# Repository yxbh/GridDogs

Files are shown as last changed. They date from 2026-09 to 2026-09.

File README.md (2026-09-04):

# GridDogs — parametric tool-anchor tiles for Gridfinity

**Pegboard tiles that drop into any Gridfinity baseplate, plus press-fit anchor pegs that
fence your tools in place.** Everything is generated from a single Python script, so every
dimension is customisable.

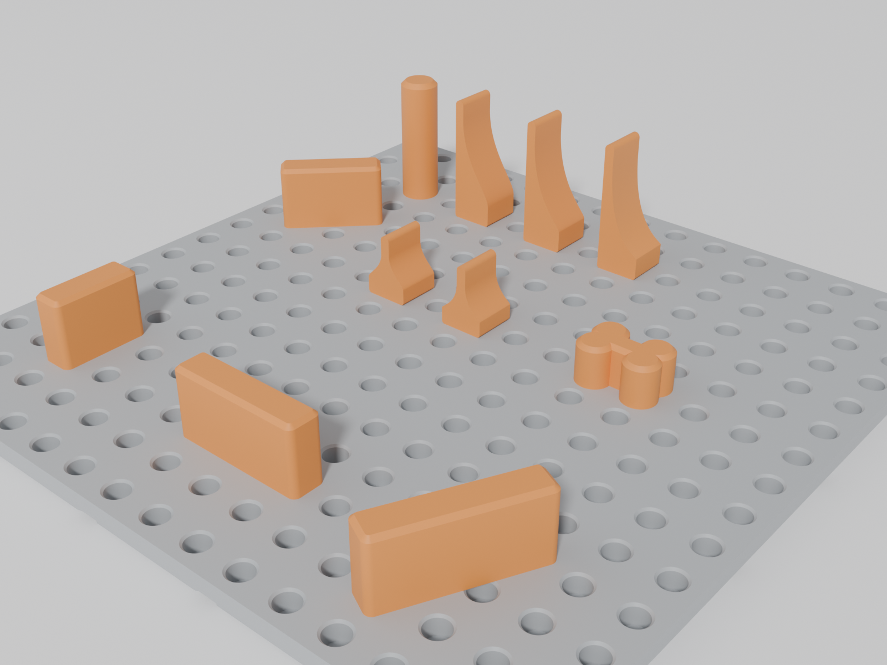
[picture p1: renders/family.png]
GridDogs family


## The idea

GridDogs combines a pegboard-style tool-retention system with the standard Gridfinity
mounting interface:

- **Tiles** are pegboard plates with standard Gridfinity feet underneath — they drop
  straight into any Gridfinity baseplate, which gives X/Y registration for free.
- **Anchors** are press-fit pegged parts that plug into the tile holes to fence tools in.
  The name comes from woodworking bench dogs.

GridDogs is *inspired by* [GridLock](https://get.gridlocksystem.com) and
[Gridfinity](https://gridfinity.xyz) (by Zack Freedman); it is not affiliated with or
endorsed by either. Its 14 mm anchor lattice is derived directly from the 42 mm
Gridfinity pitch (`42 / 3`), and its geometry is independently designed.

## Parts

| Part | Footprint | Notes |
| --- | --- | --- |
| `tile_{cols}x{rows}_gridfinity.stl` | Up to 293.5 × 293.5 mm | Every unique rectangle where `1 ≤ cols ≤ rows ≤ 7`; rotate for the opposite orientation |
| `anchor_round_bumper_{20,40}mm.stl` | 12 mm ⌀ | Single-peg round bumper with a 6.6 mm grip ridge |
| `anchor_wall_short_{20,40}mm.stl` | 26 × 10 mm | Short fence wall with two solid end pegs |
| `anchor_wall_long_{20,40}mm.stl` | 40 × 10 mm | Long fence wall with two solid end pegs and no centre peg |
| `anchor_wall_diagonal_2x2_{20,40}mm.stl` | 31.8 × 10 mm | Diagonal wall spanning a 2×2 group of holes |
| `anchor_wall_diagonal_2x3_{20,40}mm.stl` | 43.3 × 10 mm | Diagonal wall spanning a 2×3 group of holes |
| `anchor_curve_standard_{20,40}mm.stl` | 13.5 × 13.5 mm | General-purpose single-peg curved stop with a grip ridge |
| `anchor_curve_deep_{20,40}mm.stl` | 13.5 × 13.5 mm | Deeper single-peg curved stop with a grip ridge |
| `anchor_curve_bowl_{20,40}mm.stl` | 13.5 × 13.5 mm | Most aggressively scooped single-peg curved stop with a grip ridge |
| `anchor_curve_centre_standard_{20,40}mm.stl` | 13.5 × 13.5 mm | Double-sided single-peg curve with a centred peak and grip ridge |
| `anchor_curve_centre_deep_{20,40}mm.stl` | 13.5 × 13.5 mm | Deep double-sided single-peg curve with a centred peak and grip ridge |
| `anchor_bone.stl` | 24 × 17 mm | The mascot — dog-bone anchor, two pegs |
| `fit_test_coupon.stl` | 76 × 15 mm | Optional comparison strip, holes `HOLE_D ± 0.2 mm` |

Tile holes are 6.5 mm ⌀ × 5.5 mm deep blind holes on a 14 mm pitch (3 × 3 holes per
42 mm Gridfinity cell). Round and curved single-peg anchors use a 5.3 mm-long slotted
shaft with a 6.6 mm grip ridge. Wall anchors use physically tested solid 6.5 mm ⌀ ×
5.3 mm end pegs. The two-peg bone retains its shorter slotted pegs. All pegs use a
clearance-fit 7.5 mm root flare and land on the 14 mm lattice—even across adjoining
tile boundaries.

Diagonal walls use the same two solid end pegs as straight walls. The `2x2` version
connects holes one column and one row apart; the `2x3` version connects holes one column
and two rows apart. Their round pegs let each wall align naturally in either diagonal
direction as it is inserted.

## Printing

| Part | Layers | Walls | Infill | Supports | Material |
| --- | --- | --- | --- | --- | --- |
| Tiles | 0.2 mm | 3 | 10–15 % | None | PLA or PETG |
| Round, wall and bone anchors | 0.2 mm | 4 | any | None | PETG grips better than PLA |
| Curved anchors | 0.2 mm | 4 | any | Under the peg only | PETG grips better than PLA |

All STLs export in print orientation. Tiles print feet-down. Round, wall and bone anchors
print head-down with their pegs pointing upwards, so each peg grows from the supported
head and needs no support. The round and wall anchors are tall and narrow; use a 5 mm
brim.

The five curved profiles export **lying on their sides** so their profile walls print
cleanly. Their pegs are horizontal in this orientation and therefore need painted or
manual support beneath the peg only. A small flat provides a clean support interface,
and the compression slot is rotated so the press-fit crowns remain on vertical printed
walls. Being single-peg, directional curves can be aimed at any angle, but a firm knock
can swivel them; use a multi-peg wall where orientation must not move.

Functional anchors are exported in two heights: 20 mm for low-profile tools and 40 mm
for thicker handles and deeper objects. The 12 mm mascot bone is the only exception.

### Magnets (optional)

Magnet pockets are disabled by default. Set `MAGNETS = True` to add Gridfinity-standard
positions in the underside of the feet (6.3 mm ⌀ × 2.4 mm pockets for 6 × 2 mm magnets,
four per cell at 26 mm spacing). Seat or glue magnets flush with the foot face. They help
retain the tile only on a steel or magnet-equipped baseplate; they do nothing against a
plain plastic baseplate.

## Customising

Everything is driven by the `PARAMS` block at the top of
[`griddogs.py`](griddogs.py) — grid pitch, plate thickness, hole size and pitch, peg
dimensions, wall heights, magnet pockets, and the list of tile sizes to generate
(`TILES` accepts arbitrary `(cols, rows)` pairs).

The default peg shaft and hole are both 6.5 mm nominally. Single-peg anchors add a
6.6 mm rounded grip ridge to their flexible shaft, while the rounded slot termination
and solid root bridge improve strength. Wall anchors instead use two solid end pegs
because physical testing showed that slotted wall pegs could break during removal. The
peg is the preferred fit-tuning dimension because anchors are much cheaper to reprint
than tiles. If your printer or material needs a different fit, adjust `PEG_D`; the
comparison strip is not an exact thermal proxy for a full tile.
The notch count is the size index: one notch is `HOLE_D - 0.2 mm`, three is `HOLE_D`,
and five is `HOLE_D + 0.2 mm`.

The included 7×7 tile is 293.5 mm square and fits the Bambu Lab H2D's official
[325 × 320 mm single-nozzle build area](https://bambulab.com/en-us/h2d/tech-specs).
An 8×8 tile would be 335.5 mm square and does not fit.

```bash
uv run griddogs.py
```

Regenerates every STL into `stl/` and prints a watertight check, bounding box, and
volume for each part. If you don't use [uv](https://docs.astral.sh/uv/), a plain
`pip install manifold3d trimesh numpy` and `python3 griddogs.py` works too.

## Development

```bash
uv sync          # create the venv and install dependencies
uv run griddogs.py   # regenerate STLs
uv run python -m unittest tests.test_geometry
uv run ruff check .  # lint
```

Preview renders are generated headless with [Blender](https://www.blender.org):

```bash
blender --background --factory-startup --python render_previews.py
```

## Licence

[MIT](LICENSE). GridLock is a trademark of its respective owner; GridDogs is an
independent, unaffiliated open-source project.

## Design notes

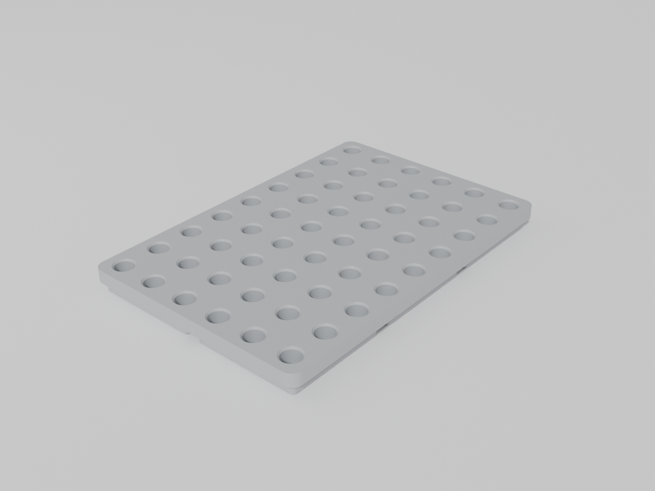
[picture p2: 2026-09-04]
renders/tile_2x3_gridfinity.png

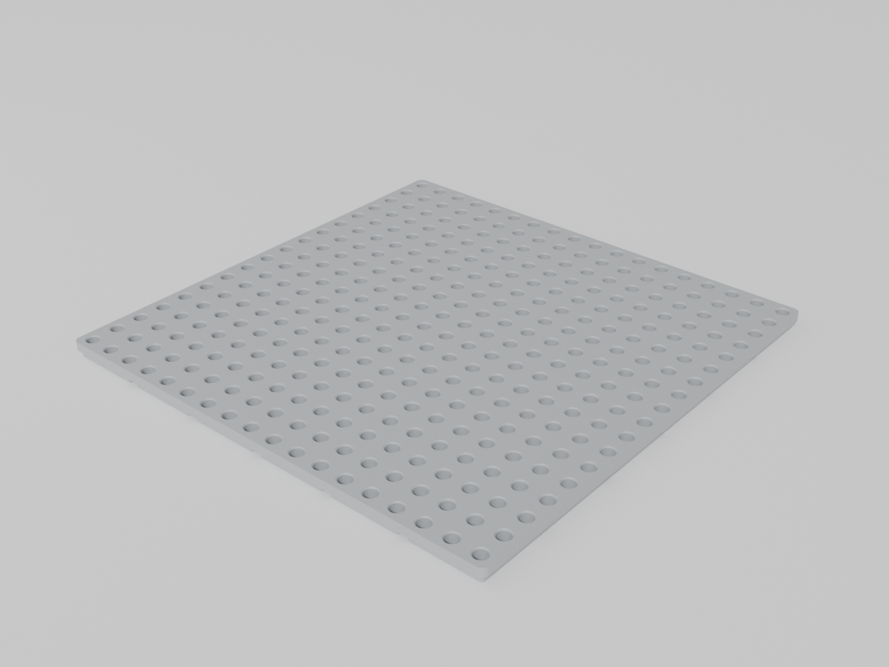
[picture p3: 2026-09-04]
renders/tile_6x6_gridfinity.png

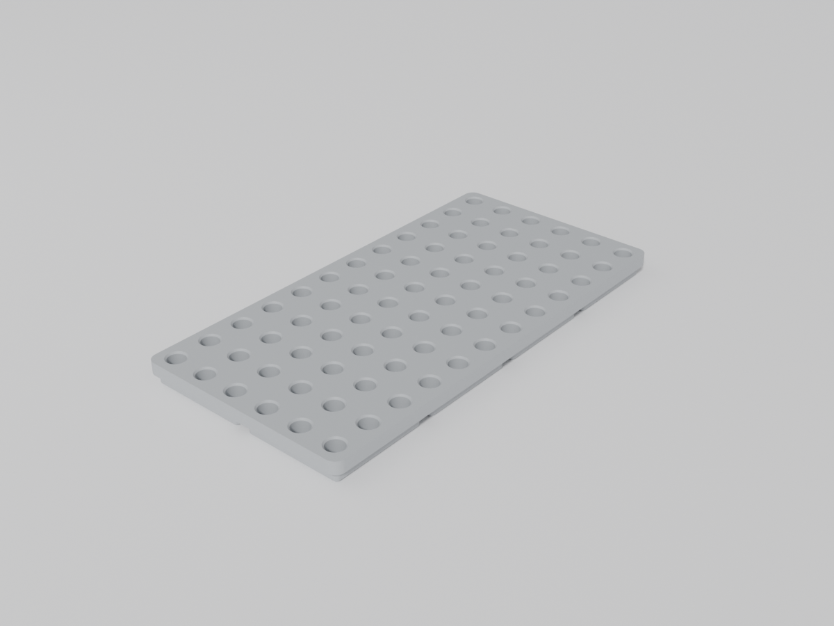
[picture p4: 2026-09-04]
renders/tile_2x4_gridfinity.png

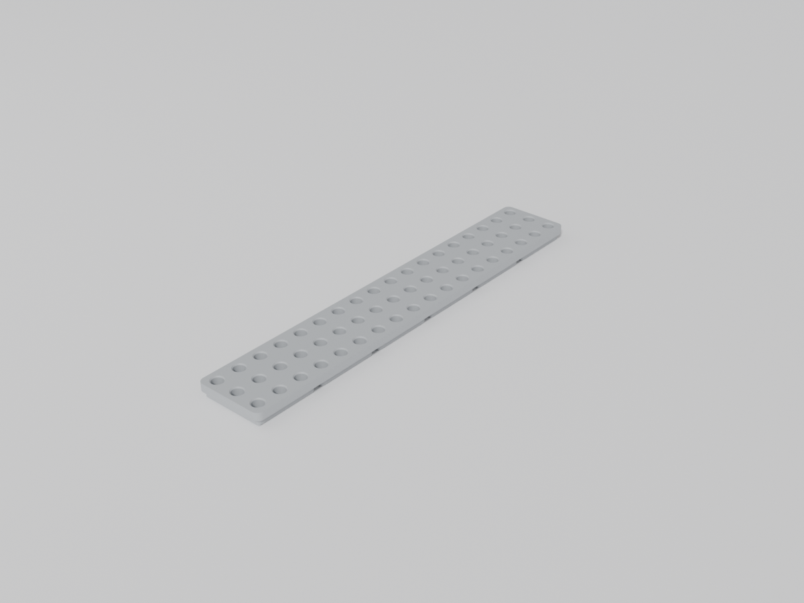
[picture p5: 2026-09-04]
renders/tile_1x6_gridfinity.png

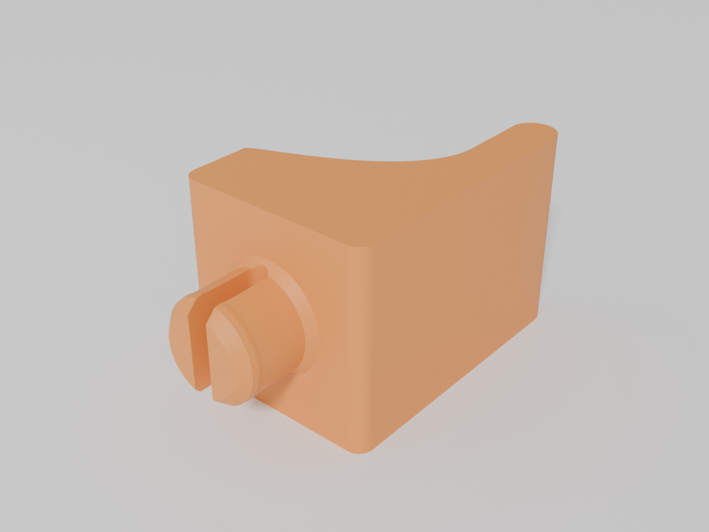
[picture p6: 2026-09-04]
renders/anchor_curve_deep_20mm.png

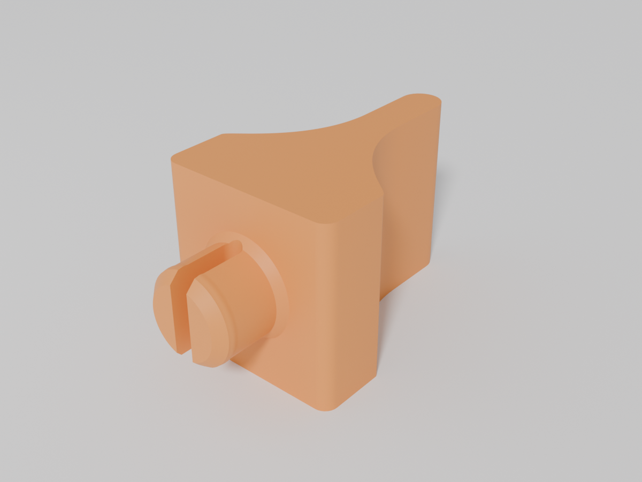
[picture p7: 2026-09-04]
renders/anchor_curve_centre_deep_20mm.png

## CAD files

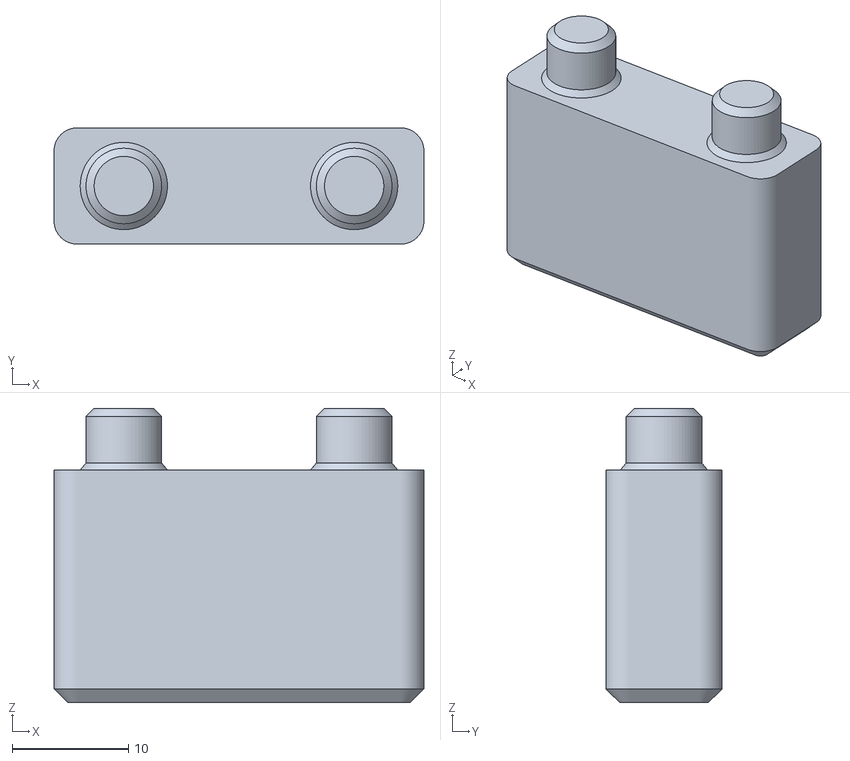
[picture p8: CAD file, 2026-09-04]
stl/anchor_wall_diagonal_2x2_20mm.stl
31.8 x 10.0 x 25.3

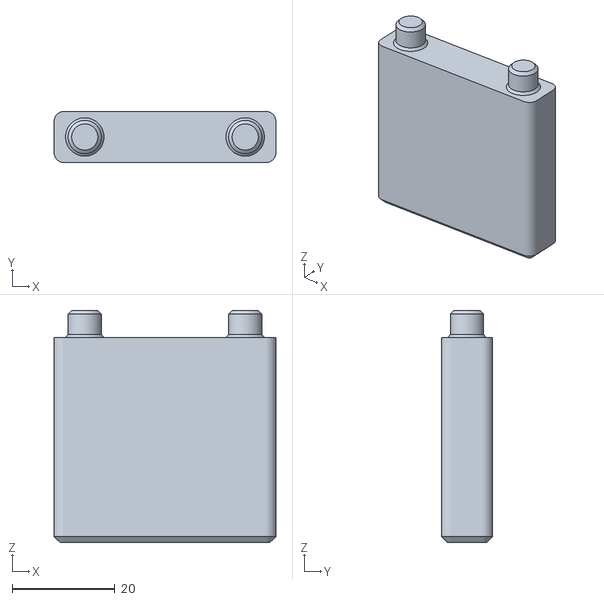
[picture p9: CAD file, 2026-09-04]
stl/anchor_wall_diagonal_2x3_40mm.stl
43.3 x 10.0 x 45.3

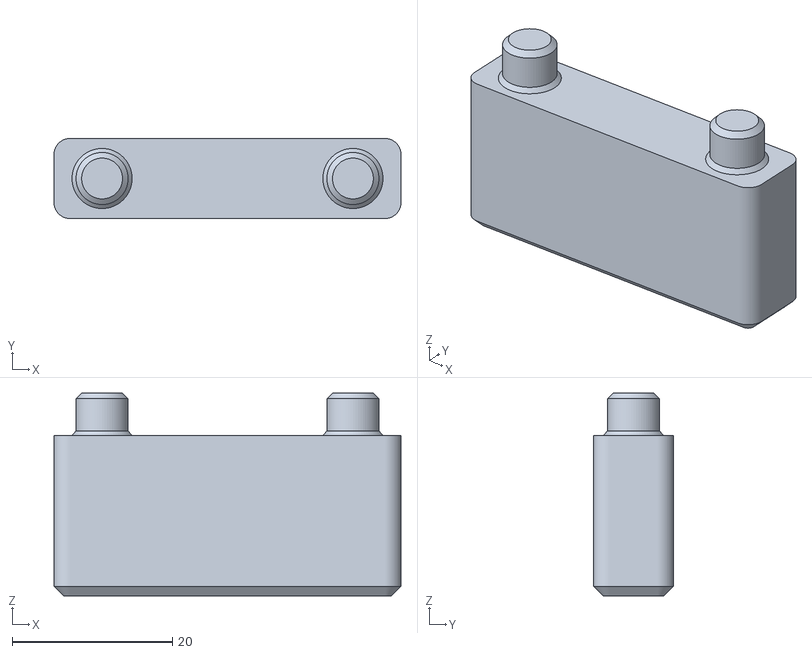
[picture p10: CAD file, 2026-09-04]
stl/anchor_wall_diagonal_2x3_20mm.stl
43.3 x 10.0 x 25.3

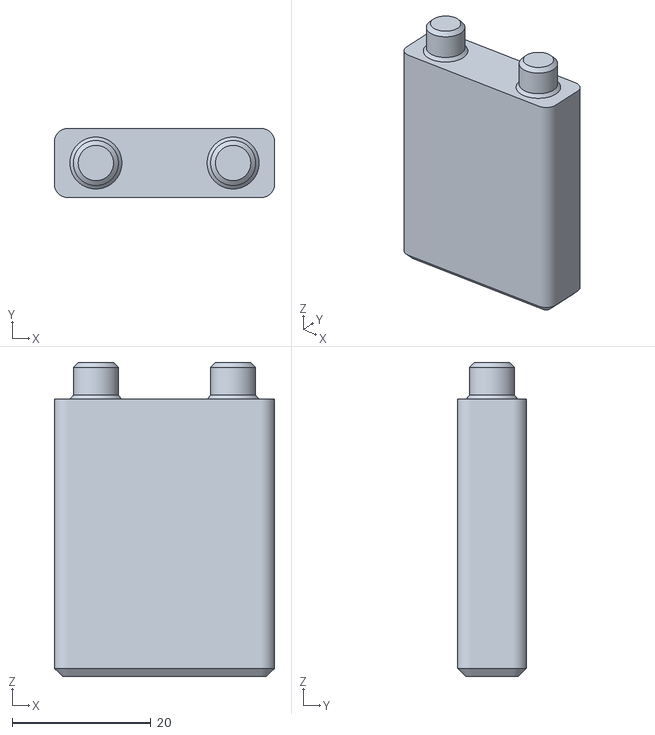
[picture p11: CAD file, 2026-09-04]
stl/anchor_wall_diagonal_2x2_40mm.stl
31.8 x 10.0 x 45.3

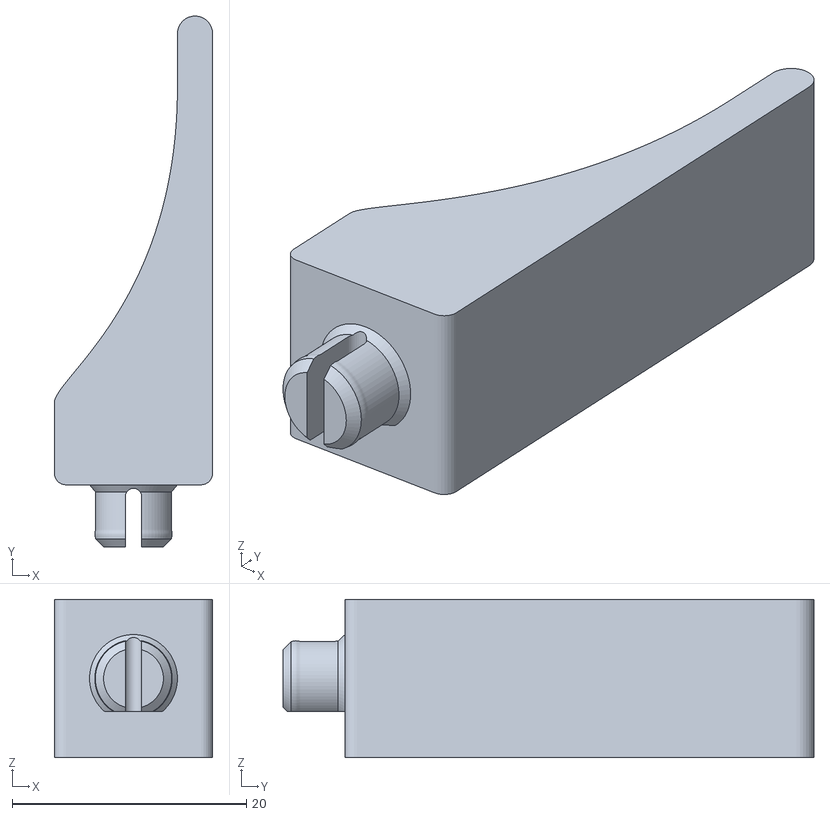
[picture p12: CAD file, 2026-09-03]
stl/anchor_curve_deep_40mm.stl
13.5 x 45.3 x 13.5

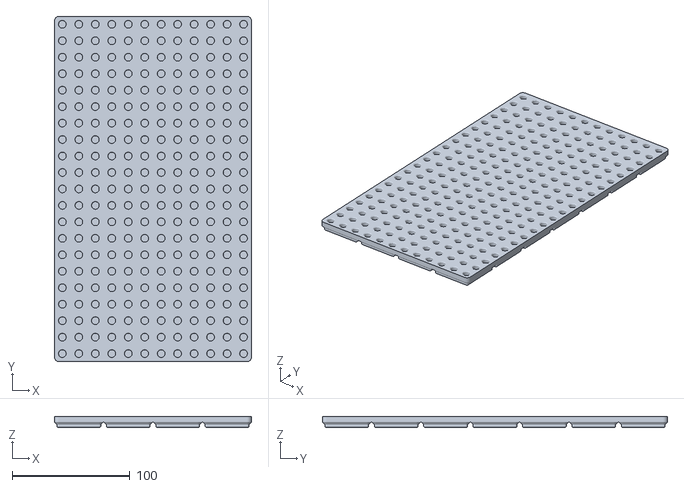
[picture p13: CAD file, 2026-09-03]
stl/tile_4x7_gridfinity.stl
167.5 x 293.5 x 9.50

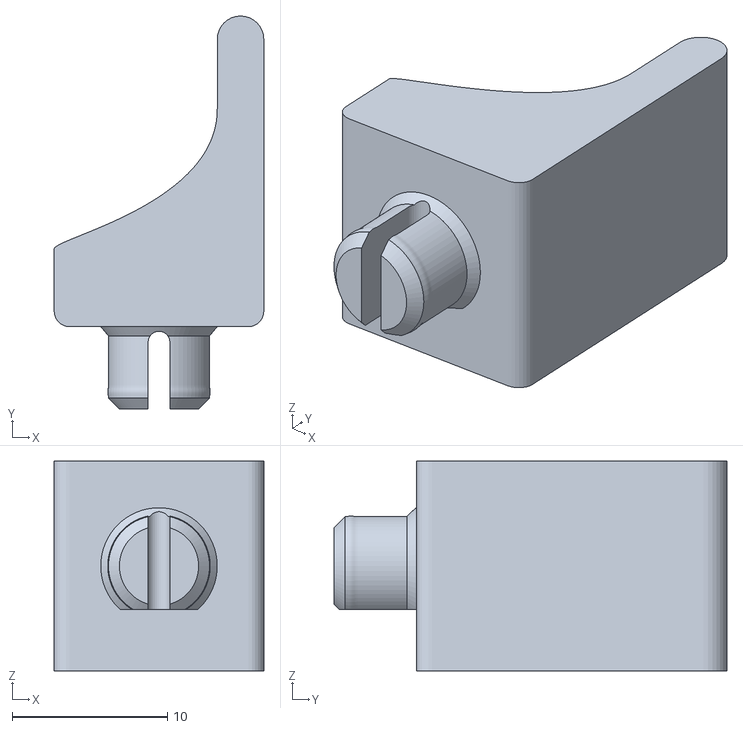
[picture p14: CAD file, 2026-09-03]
stl/anchor_curve_deep_20mm.stl
13.5 x 25.3 x 13.5

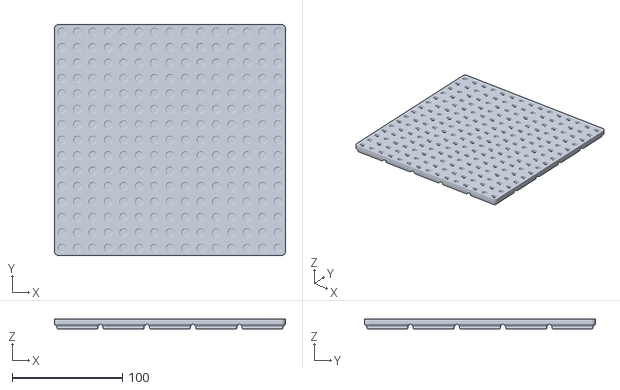
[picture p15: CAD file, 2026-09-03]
stl/tile_5x5_gridfinity.stl
209.5 x 209.5 x 9.50

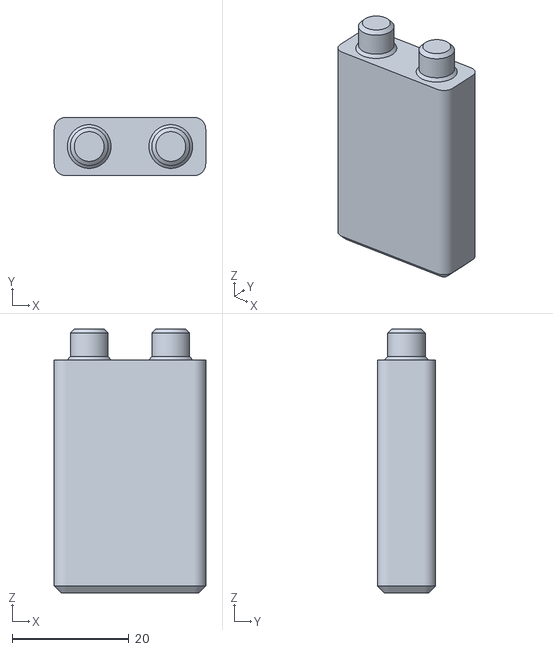
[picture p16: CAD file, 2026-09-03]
stl/anchor_wall_short_40mm.stl
26.0 x 10.0 x 45.3

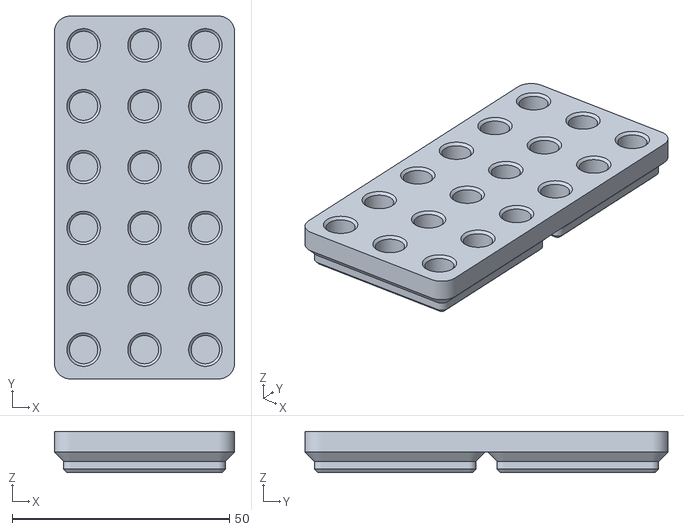
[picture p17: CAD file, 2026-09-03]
stl/tile_1x2_gridfinity.stl
41.5 x 83.5 x 9.50

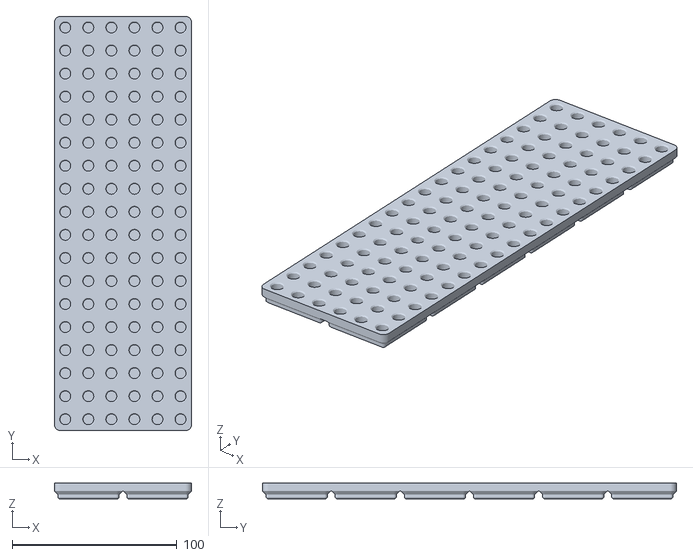
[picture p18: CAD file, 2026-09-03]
stl/tile_2x6_gridfinity.stl
83.5 x 251.5 x 9.50

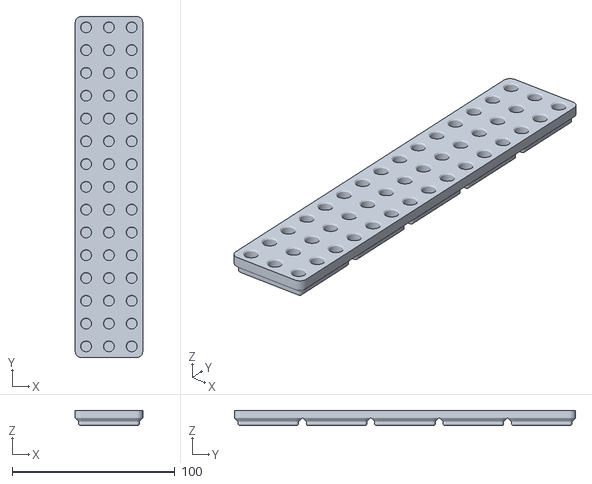
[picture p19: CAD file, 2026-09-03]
stl/tile_1x5_gridfinity.stl
41.5 x 209.5 x 9.50

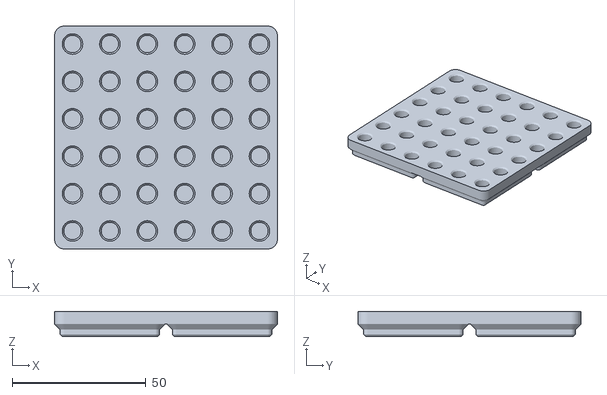
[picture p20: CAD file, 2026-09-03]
stl/tile_2x2_gridfinity.stl
83.5 x 83.5 x 9.50

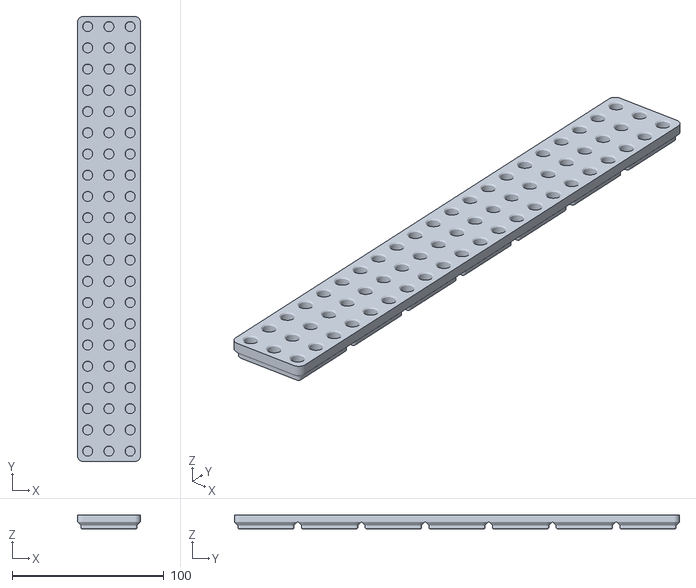
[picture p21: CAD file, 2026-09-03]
stl/tile_1x7_gridfinity.stl
41.5 x 293.5 x 9.50

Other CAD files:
stl/anchor_curve_centre_deep_40mm.stl
stl/tile_1x1_gridfinity.stl
stl/tile_2x3_gridfinity.stl
stl/tile_6x7_gridfinity.stl
stl/anchor_bone.stl
stl/anchor_curve_bowl_20mm.stl
stl/anchor_curve_bowl_40mm.stl
stl/anchor_curve_centre_deep_20mm.stl
stl/anchor_curve_centre_standard_20mm.stl
stl/anchor_curve_centre_standard_40mm.stl
stl/anchor_curve_standard_20mm.stl
stl/anchor_curve_standard_40mm.stl
stl/anchor_round_bumper_20mm.stl
stl/anchor_round_bumper_40mm.stl
stl/anchor_wall_long_20mm.stl
stl/anchor_wall_long_40mm.stl
stl/anchor_wall_short_20mm.stl
stl/fit_test_coupon.stl
stl/tile_1x3_gridfinity.stl
stl/tile_1x4_gridfinity.stl
stl/tile_1x6_gridfinity.stl
stl/tile_2x4_gridfinity.stl
stl/tile_2x5_gridfinity.stl
stl/tile_2x7_gridfinity.stl
stl/tile_3x3_gridfinity.stl
stl/tile_3x4_gridfinity.stl
stl/tile_3x5_gridfinity.stl
stl/tile_3x6_gridfinity.stl
stl/tile_3x7_gridfinity.stl
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

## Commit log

2026-08-23 Add the parametric tile and anchor generator
    Generate Gridfinity-footed tiles on a 14 mm anchor lattice, reinforced press-fit anchors in 20 mm and 40 mm heights, and geometry regression tests.
    Copilot-Session: 0bd1250b-d929-4d53-9f9b-56e7f5108f3c
2026-08-23 Document GridDogs parts and printing
    Describe the tile catalogue, anchor variants, honest support requirements, customisation, H2D limits, and project attribution.
    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
2026-08-23 Add generated STL catalogue
    Include all 28 H2D-compatible rectangular tiles, reinforced anchor variants, the mascot, and the optional fit comparison strip.
    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
    [anchor_bone.stl, anchor_curve_bowl_20mm.stl, anchor_curve_bowl_40mm.stl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]
2026-08-23 Add generated preview renders
    Include one preview per STL and the complete anchor-family hero render.
    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
2026-08-28 Reinforce anchor peg roots
    Use matched 6.5 mm peg and hole diameters, add a solid rounded slot termination at the peg root, disable magnets by default, and refresh generated parts and previews.
    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
    [anchor_bone.stl, anchor_curve_bowl_20mm.stl, anchor_curve_bowl_40mm.stl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]
2026-09-03 Adopt tested anchor peg designs
    Deepen tile holes to 5.5 mm, use solid 6.5 x 5.3 mm end pegs on wall anchors, and apply the 6.6 mm grip ridge to all single-peg anchors. Rename wall outputs and refresh generated STLs and previews.
    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
    [anchor_bone.stl, anchor_curve_bowl_20mm.stl, anchor_curve_bowl_40mm.stl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]
2026-09-04 Add diagonal wall anchors
    Generate 2x2 and 2x3 diagonal walls at both standard heights, document their lattice spans, and expand the family preview to show the complete anchor range.
    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
    [anchor_wall_diagonal_2x2_20mm.stl, anchor_wall_diagonal_2x2_40mm.stl, anchor_wall_diagonal_2x3_20mm.stl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]
